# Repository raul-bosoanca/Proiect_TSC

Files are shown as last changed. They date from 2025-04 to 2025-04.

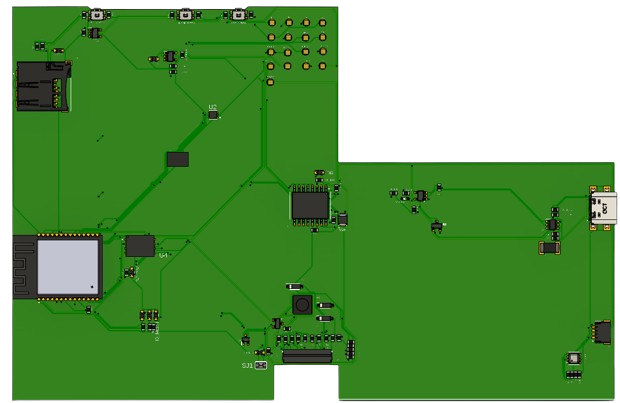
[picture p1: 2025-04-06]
Images/board_top_view.png

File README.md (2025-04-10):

# Proiect_TSC

Diagrama_Block_Openbook drawio

BOM (Bill of Materials):

| Item | Product Link | Datasheet Link |
|---|---|---|
| 112A-TAAR-R03 | [Product](https://store.comet.srl.ro/Catalogue/Product/43497/) | [Datasheet](https://store.comet.bg/download-file.php?id=27596) |
| BD5229G-TR | [Product](https://store.comet.srl.ro/Catalogue/Product/43497/) | [Datasheet](https://datasheet.datasheetarchive.com/originals/distributors/Datasheets_SAMA/f2b9741ef86007909f138d561a359946.pdf) |
| Capacitor 0402 | [Product](https://store.comet.srl.ro/Catalogue/Product/43497/) | [Datasheet](https://componentsearchengine.com/Datasheets/2/CC0402MRX5R5BB106.pdf) |
| CPH3225A | [Product](https://store.comet.srl.ro/Catalogue/Product/43497/) | [Datasheet](https://www.snapeda.com/parts/CPH3225A/Seiko%20Instruments/datasheet/) |
| DS3231SN RTC | [Product](https://store.comet.srl.ro/Catalogue/Product/43497/) | [Datasheet](https://www.snapeda.com/parts/DS3231SN%23/Analog%20Devices/datasheet/) |
| ESP32 WROVER 0805 Capacitor | [Product](https://store.comet.srl.ro/Catalogue/Product/43497/) | [Datasheet](https://ro.mouser.com/datasheet/2/40/schottky-3165252.pdf) |
| ESP32 WROVER BME680 Sensor | [Product](https://store.comet.srl.ro/Catalogue/Product/43497/) | [Datasheet](https://www.snapeda.com/parts/BME680/Bosch%20Sensortec/datasheet/) |
| ESP32 WROVER MCP73831 Power Management | [Product](https://store.comet.srl.ro/Catalogue/Product/43497/) | [Datasheet](https://eu.mouser.com/datasheet/2/268/MCP73831_Family_Data_Sheet_DS20001984H-3441711.pdf) |
| ESP32 WROVER P-Channel MOSFET | [Product](https://store.comet.srl.ro/Catalogue/Product/43497/) | [Datasheet](https://www.diodes.com/assets/Datasheets/DMG2305UX.pdf) |
| ESP32C6 Varistor 1812 | [Product](https://store.comet.srl.ro/Catalogue/Product/43497/) | [Datasheet](https://www.tdk-electronics.tdk.com/inf/75/db/CTVS_14/Surge_protection_series.pdf) |
| ESP32-C6 WROOM-1-N8 | [Product](https://store.comet.srl.ro/Catalogue/Product/43497/) | [Datasheet](https://www.snapeda.com/parts/ESP32-C6-WROOM-1-N8/Espressif%20Systems/datasheet/) |
| FH34SRJ-24S-0.5SH Connector | [Product](https://store.comet.srl.ro/Catalogue/Product/43497/) | [Datasheet](https://www.hirose.com/en/product/document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) |
| LED Chip 0603 | [Product](https://store.comet.srl.ro/Catalogue/Product/43497/) | [Datasheet](https://www.snapeda.com/parts/KP-1608SURCK/Kingbright/datasheet/) |
| MAX17048G+T10 Battery Fuel Gauge | [Product](https://store.comet.srl.ro/Catalogue/Product/43497/) | [Datasheet](https://www.snapeda.com/parts/MAX17048G+T10/Analog%20Devices/datasheet/) |
| MBR0530 Schottky Diode | [Product](https://store.comet.srl.ro/Catalogue/Product/43497/) | [Datasheet](https://www.snapeda.com/parts/MBR0530/ON%20Semiconductor/datasheet/) |
| PGB1010603MR Inductor | [Product](https://store.comet.srl.ro/Catalogue/Product/43497/) | [Datasheet](https://www.snapeda.com/parts/PGB1010603MR/Littelfuse%20Inc./datasheet/) |
| QWIIC Connector | [Product](https://store.comet.srl.ro/Catalogue/Product/43497/) | [Datasheet](https://www.youtube.com/watch?v=dQw4w9WgXcQ) |
| RCL CPOL 3528 | [Product](https://store.comet.srl.ro/Catalogue/Product/43497/) | [Datasheet](https://s3.amazonaws.com/snapeda/datasheet/TAJB475K025RNJ_AVX.pdf) |
| SI1308EDL-T1-GE3 MOSFET | [Product](https://store.comet.srl.ro/Catalogue/Product/43497/) | [Datasheet](https://www.youtube.com/watch?v=dQw4w9WgXcQ) |
| SJ | [Product](https://store.comet.srl.ro/Catalogue/Product/43497/) | [Datasheet](https://www.youtube.com/watch?v=dQw4w9WgXcQ) |
| TPTP20R | [Product](https://store.comet.srl.ro/Catalogue/Product/43497/) | [Datasheet](https://easyeda.com/component/7524403feb2642ac9f9f26dfb93ceacf) |
| USB4110-GF-A USB Hub | [Product](https://store.comet.srl.ro/Catalogue/Product/43497/) | [Datasheet](https://gct.co/files/drawings/usb4110.pdf) |
| USBLC6-2SC6Y USB Surge Protection | [Product](https://store.comet.srl.ro/Catalogue/Product/43497/) | [Datasheet](https://www.snapeda.com/parts/USBLC6-2SC6Y/STMicroelectronics/datasheet/) |
| XC6220A331MR-G Voltage Regulator | [Product](https://store.comet.srl.ro/Catalogue/Product/43497/) | [Datasheet](https://product.torexsemi.com/system/files/series/xc6220.pdf) |

  Hardware Components:

  ESP32-C3-WROOM:
    
    Wi-Fi/BLE connectivity
    Supports SPI, I2C, and UART communication
    Operates at 3.3V, powered by an LDO regulator

  USB-C - Charging & USB communication
  
  MCP73832 - LiPo battery charging management
  
  LDO 3.3V - Supplies power to ESP32 and peripherals
  
  DC/DC 5V - Provides 5V for sensors
  
  BME680 - Enveroment sensor

ESP32 PINOUT:

    IO0 - RTC INT Signal
    IO1 - CLOCK Signal
    IO2 - SPI MISO Signal
    IO3 - EPD BUSY Signal
    IO4 - SD Card Chip Select
    IO5 - EPD DC Signal
    IO6 - SPI SCK Signal
    IO7 - SPI MOSI Signal
    IO9 - BOOT Button Signal
    IO10 - EPD Chip Select
    IO11 - Flash NOR Memory Chip Select
    IO12 - USB D+ Signal
    IO13 - USB D- Signal
    IO15 - CHANGE Button Signal
    GPIO16 - UART TX
    GPIO17 - UART RX
    IO18 - RTC RESET Signal
    IO19 - I2C Sensor VDDIO Signal
    IO20 - EPD 3V3
    IO21 - I2C SDA Signal
    IO22 - I2C SCL Signal
    IO23 - EPD RESET Signal

Note : On the final 3D models i did not render the top and buttom ground planes because the working pc did not have the power to render them

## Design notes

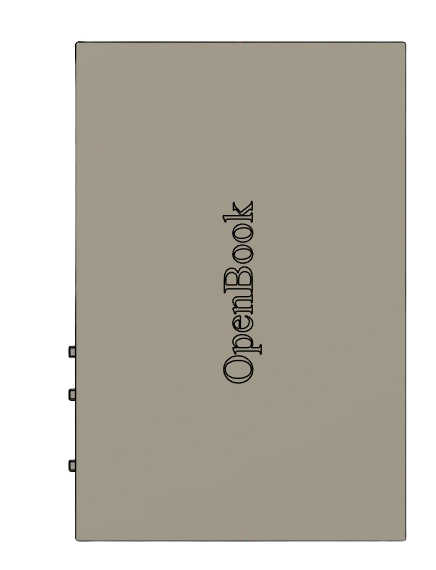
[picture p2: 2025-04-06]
Images/open_book_bottom.png

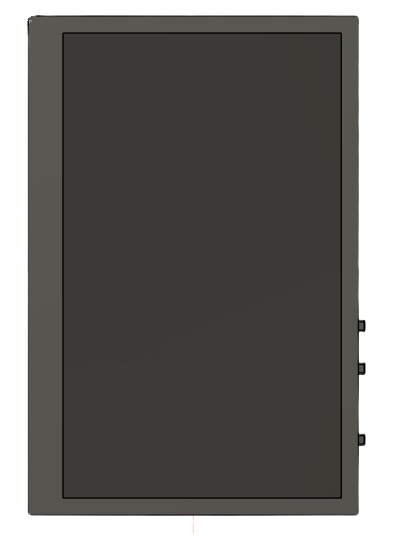
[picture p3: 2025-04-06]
Images/open_book_top.png

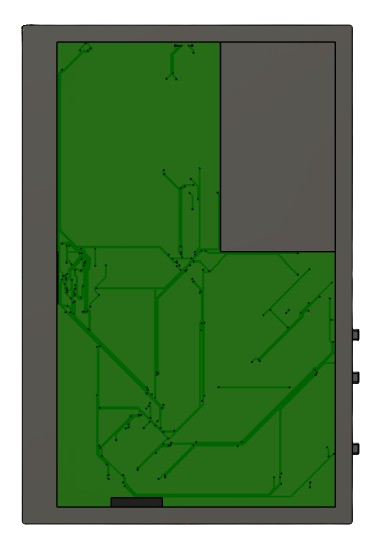
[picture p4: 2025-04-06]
Images/open_book_top_no_screen.png

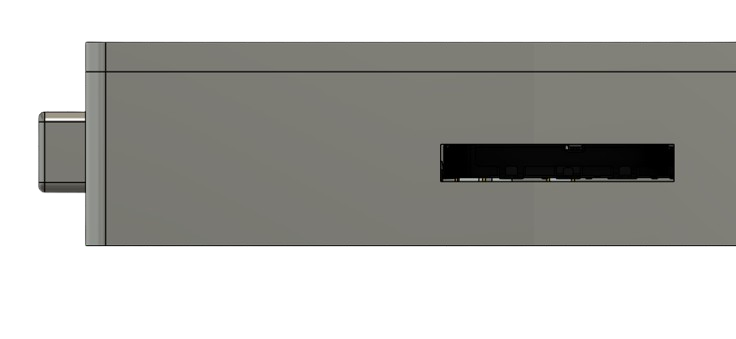
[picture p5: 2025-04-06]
Images/open_book_sd_port.png

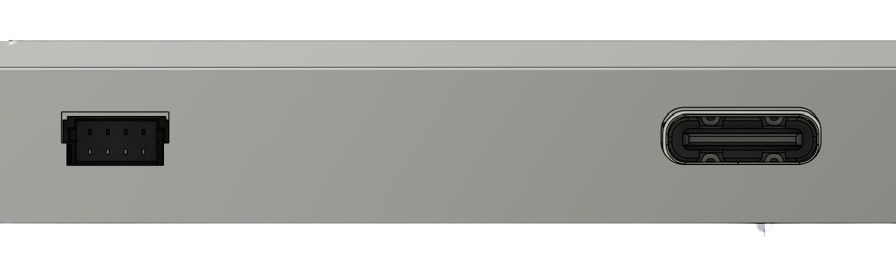
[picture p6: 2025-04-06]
Images/open_book_usb_ports.png

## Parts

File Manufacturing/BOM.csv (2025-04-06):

Qty | Value | Device | Package | Parts | Description | ARROW_PART_NUMBER | ARROW_PRICE-STOCK | AVAILABILITY | CENTROID_NOT_SPECIFIED | CHECK_PRICES | COPYRIGHT | DATASHEET | DESCRIPTION | DIGIKEY_DESCRIPTION | DIGIKEY_PART_NUMBER | HEIGHT | LEAD_FREE | MANUFACTURER_NAME | MANUFACTURER_PART_NUMBER | MF | MFR_NAME | MOUSER_PART_NUMBER | MOUSER_PRICE-STOCK | MOUSER_TESTING_PART_NUMBER | MOUSER_TESTING_PRICE-STOCK | MP | MPN | PACKAGE | POPULARITY | PREFIX | PRICE | PROD_ID | PURCHASE-URL | ROHS | SNAPEDA_LINK | SPICEMODEL | SPICEPREFIX | TEMPERATURE_RANGE_HIGH | TEMPERATURE_RANGE_LOW | TP_SIGNAL_NAME | VALUE
1 |  | ADAFRUIT_LEDCHIP-LED0603 | ADAFRUIT_CHIP-LED0603 | CHG_LED | LED
1 |  | SJ | SJ | SJ1 | SMD solder JUMPER |  |  |  |  |  |  |  |  |  |  |  |  |  |  |  |  |  |  |  |  |  |  |  | 3
1 | 0.47 | ESP32_WROVER_EAGLE-LTSPICE_RR0402 | EAGLE-LTSPICE_C0402 | R4 | RESISTOR, European symbol |  |  |  |  |  |  |  |  |  |  |  |  |  |  |  |  |  |  |  |  |  |  |  |  |  |  |  |  |  |  | NONE | R
1 | 100K | ESP32_WROVER_EAGLE-LTSPICE_RR0402 | EAGLE-LTSPICE_C0402 | R1_PWRUSB | RESISTOR, European symbol |  |  |  |  |  |  |  |  |  |  |  |  |  |  |  |  |  |  |  |  |  |  |  |  |  |  |  |  |  |  | NONE | R
4 | 100nF | EAGLE-LTSPICE_CC0402 | EAGLE-LTSPICE_C0402 | C17, C18, C19, C23 | CAPACITOR, European symbol |  |  |  |  |  |  |  |  |  |  |  |  |  |  |  |  |  |  |  |  |  |  |  |  |  |  |  |  |  |  | NONE | C
2 | 100nF | ESP32_WROVER_EAGLE-LTSPICE_CC0402 | EAGLE-LTSPICE_C0402 | C1, C9 | CAPACITOR, European symbol |  |  |  |  |  |  |  |  |  |  |  |  |  |  |  |  |  |  |  |  |  |  |  |  |  |  |  |  |  |  | NONE | C
2 | 100uF | EAGLE-LTSPICE_CC0402 | EAGLE-LTSPICE_C0402 | C21, C22 | CAPACITOR, European symbol |  |  |  |  |  |  |  |  |  |  |  |  |  |  |  |  |  |  |  |  |  |  |  |  |  |  |  |  |  |  | NONE | C
1 | 100uF | RCL_CPOL-EUCT3528 | RCL_CT3528 | C4 | POLARIZED CAPACITOR, European symbol |  |  |  |  |  |  |  |  |  |  |  |  |  |  |  |  |  |  |  |  |  |  |  | 0 |  |  |  |  |  |  |  | C
7 | 10K | ESP32_WROVER_EAGLE-LTSPICE_RR0402 | EAGLE-LTSPICE_C0402 | R1-PINH1, R2-PINH1, R3, R5, R6, R7, R_CL1 | RESISTOR, European symbol |  |  |  |  |  |  |  |  |  |  |  |  |  |  |  |  |  |  |  |  |  |  |  |  |  |  |  |  |  |  | NONE | R
9 | 10k | ESP32_WROVER_EAGLE-LTSPICE_RR0402 | EAGLE-LTSPICE_C0402 | R_BOOT, R_CHANGE, R_EPD_CS, R_FLASH_CS, R_MISO, R_MOSI', R_RESET, R_SCK, R_SS_SD | RESISTOR, European symbol |  |  |  |  |  |  |  |  |  |  |  |  |  |  |  |  |  |  |  |  |  |  |  |  |  |  |  |  |  |  | NONE | R
1 | 10uF | ESP32_WROVER_EAGLE-LTSPICE_CC0402 | EAGLE-LTSPICE_C0402 | C3 | CAPACITOR, European symbol |  |  |  |  |  |  |  |  |  |  |  |  |  |  |  |  |  |  |  |  |  |  |  |  |  |  |  |  |  |  | NONE | C
1 | 112A-TAAR-R03_ATTEND | 112A-TAAR-R03_ATTEND | 112ATAARR03ATTEND | J2 | Micro SD Card Socket, Push-Push Type, Top Mount, SMT, H=1.83mm, 10u |  |  |  |  |  |  |  | Micro SD Card Socket | Push-Push Type | Top Mount | SMT | H=1.83mm | 10u |  |  | 1.9mm |  | ATTEND | 112A-TAAR-R03 ATTEND
1 | 15 | ESP32_WROVER_EAGLE-LTSPICE_RR0402 | EAGLE-LTSPICE_C0402 | R10 | RESISTOR, European symbol |  |  |  |  |  |  |  |  |  |  |  |  |  |  |  |  |  |  |  |  |  |  |  |  |  |  |  |  |  |  | NONE | R
1 | 1uF | EAGLE-LTSPICE_CC0402 | EAGLE-LTSPICE_C0402 | C20 | CAPACITOR, European symbol |  |  |  |  |  |  |  |  |  |  |  |  |  |  |  |  |  |  |  |  |  |  |  |  |  |  |  |  |  |  | NONE | C
10 | 1uF/50V | EAGLE-LTSPICE_CC0402 | EAGLE-LTSPICE_C0402 | C6, C7, C8, C10, C11, C12, C13, C14, C15, C16 | CAPACITOR, European symbol |  |  |  |  |  |  |  |  |  |  |  |  |  |  |  |  |  |  |  |  |  |  |  |  |  |  |  |  |  |  | NONE | C
1 | 2.2 | ESP32_WROVER_EAGLE-LTSPICE_RR0402 | EAGLE-LTSPICE_C0402 | R2 | RESISTOR, European symbol |  |  |  |  |  |  |  |  |  |  |  |  |  |  |  |  |  |  |  |  |  |  |  |  |  |  |  |  |  |  | NONE | R
1 | 200 | ESP32_WROVER_EAGLE-LTSPICE_RR0402 | EAGLE-LTSPICE_C0402 | R1_BAT | RESISTOR, European symbol |  |  |  |  |  |  |  |  |  |  |  |  |  |  |  |  |  |  |  |  |  |  |  |  |  |  |  |  |  |  | NONE | R
2 | 20V/4.2A/52mO/1.4W | ESP32_WROVER_SPARKFUN-DISCRETESEMI_MOSFET_PCH-DMG2305UX-7 | ESP32_WROVER_SPARKFUN-DISCRETESEMI_SOT23-3 | Q1, Q3 | P-channel MOSFETs |  |  |  |  |  |  |  |  |  |  |  |  |  |  |  |  |  |  |  |  |  |  |  |  |  |  | TRAN-14388 |  |  |  |  |  |  |  |  | 20V/4.2A/52mO/1.4W
1 | 2K | ESP32_WROVER_EAGLE-LTSPICE_RR0402 | EAGLE-LTSPICE_C0402 | R2_BAT | RESISTOR, European symbol |  |  |  |  |  |  |  |  |  |  |  |  |  |  |  |  |  |  |  |  |  |  |  |  |  |  |  |  |  |  | NONE | R
5 | 4.7uF | ESP32_WROVER_EAGLE-LTSPICE_CC0402 | EAGLE-LTSPICE_C0402 | C1_BAT, C1_BAT1, C1_BAT2, C2, C2_BAT | CAPACITOR, European symbol |  |  |  |  |  |  |  |  |  |  |  |  |  |  |  |  |  |  |  |  |  |  |  |  |  |  |  |  |  |  | NONE | C
1 | 4.7uF/25V | ESP32_WROVER_EAGLE-LTSPICE_CC0402 | EAGLE-LTSPICE_C0402 | C5 | CAPACITOR, European symbol |  |  |  |  |  |  |  |  |  |  |  |  |  |  |  |  |  |  |  |  |  |  |  |  |  |  |  |  |  |  | NONE | C
2 | 5k1 | ESP32_WROVER_EAGLE-LTSPICE_RR0402 | EAGLE-LTSPICE_C0402 | R2-USB_5K1, R2-USB_5K2 | RESISTOR, European symbol |  |  |  |  |  |  |  |  |  |  |  |  |  |  |  |  |  |  |  |  |  |  |  |  |  |  |  |  |  |  | NONE | R
1 | 68Uh | 744043680IND_4828-WE-TPC_WRE | IND_4828-WE-TPC_WRE | L1 |  |  |  |  |  |  | Copyright (C) 2024 Ultra Librarian. All rights reserved. |  |  |  |  |  |  |  | 744043680 |  | Wurth Electronics
1 | BD5229G-TR | BD5229G-TR | SOT95P280X125-5N | IC2 | Voltage Detector with Adjustable Delay Time: CMOS processes are utilized to develop high precision, low current consumption CMOS reset ICs that allow arbitrary setting of the delay time. The extensive lineup includes both Nch Open Drain and CMOS output types in a wide range of detection voltages (from 2.3V to 6.0V, in 0.1V steps), enabling selection of the ideal solution based on customer requirements. In addition, the entire series is of course both lead-free and RoHS-compliant. |  |  |  |  |  |  |  | Voltage Detector with Adjustable Delay Time: CMOS processes are utilized to develop high precision | low current consumption CMOS reset ICs that allow arbitrary setting of the delay time. The extensive lineup includes both Nch Open Drain and CMOS output types in a wide range of detection voltages (from 2.3V to 6.0V | in 0.1V steps) | enabling selection of the ideal solution based on customer requirements. In addition | the entire series is of course both lead-free and RoHS-compliant. |  |  | 1.25mm |  | ROHM Semiconductor | BD5229G-TR |  |  | 755-BD5229G-TR | https://www.mouser.co.uk/ProductDetail/ROHM-Semiconductor/BD5229G-TR?qs=4kLU8WoGk0vvnhrrYwdszw%3D%3D
3 | BUTTON_CUSYOMV1 | BUTTON_CUSYOMV1 | MYBUTTON | BOOT_BUTTON, CHANGE_BUTTON, RESET_BUTTON
1 | CPH3225A | CPH3225A | CAPCP3225X100N | C24 | Cap 0.011F 3.3V 1210 Flat Check availability |  |  | Not in stock |  | https://www.snapeda.com/parts/CPH3225A/Seiko+Instruments/view-part/?ref=eda |  |  | 11 mF (EDLC) Supercapacitor 3.3 V 1210 (3225 Metric) - - |  |  |  |  |  |  | Seiko Instruments |  |  |  |  |  | CPH3225A |  | 1210 Seiko |  |  | None |  | https://www.snapeda.com/api/url_track_click_mouser/?unipart_id=562593&manufacturer=Seiko Instruments&part_name=CPH3225A&search_term=None |  | https://www.snapeda.com/parts/CPH3225A/Seiko+Instruments/view-part/?ref=snap
1 | DS3231SN# | DS3231SN# | SOIC127P1032X265-16N | U3 | Real Time Clock Serial 16-Pin SOIC W T/R Check availability |  |  | In Stock |  | https://www.snapeda.com/parts/DS3231SN%23/Analog+Devices/view-part/?ref=eda |  |  | Extremely Accurate I²C-Integrated RTC/TCXO/Crystal |  |  |  |  |  |  | Analog Devices |  |  |  |  |  | DS3231SN# |  | SOIC-16 Maxim |  |  | None |  | https://www.snapeda.com/api/url_track_click_mouser/?unipart_id=99048&manufacturer=Analog Devices&part_name=DS3231SN#&search_term=None |  | https://www.snapeda.com/parts/DS3231SN%23/Analog+Devices/view-part/?ref=snap
1 | ESP32-C6-WROOM-1-N8 | ESP32-C6-WROOM-1-N8 | XCVR_ESP32-C6-WROOM-1-N8 | U1 | Check availability |  |  | In Stock |  | https://www.snapeda.com/parts/ESP32-C6-WROOM-1-N8/Espressif+Systems/view-part/?ref=eda |  |  | Multiprotocol Modules ESP32-C6 module | Wi-Fi 6 in 2.4 GHz band | Bluetooth 5 | Zigbee 3.0 and Thread. ESP34-WROOM Compatible - ENGINEERING SAMPLE |  |  |  |  |  |  | Espressif Systems |  |  |  |  |  | ESP32-C6-WROOM-1-N8 |  | None |  |  | None |  |  |  | https://www.snapeda.com/parts/ESP32-C6-WROOM-1-N8/Espressif+Systems/view-part/?ref=snap
1 | ESP32C6_VARISTORCN1812 | ESP32C6_VARISTORCN1812 | ESP32C6_VARISTOR_CT/CN1812 | R1 | VARISTOR |  |  |  |  |  |  |  |  |  |  |  |  |  |  |  |  |  |  |  |  |  |  |  | 0
2 | ESP32_WROVER_AVX---SD0805S020S1R0_AVX_SD0805S020S1R0_0_0AVX_SD0805S020S1R0_0_0 | ESP32_WROVER_AVX---SD0805S020S1R0_AVX_SD0805S020S1R0_0_0AVX_SD0805S020S1R0_0_0 | ESP32_WROVER_AVX---SD0805S020S1R0_AVX_SD0805S020S1R0_0 | D2, D6 | Schottky Barrier Rectifier Diode |  |  |  | No |  |  | http://datasheets.avx.com/schottky.pdf |  | DIODE SCHOTTKY 20V 1A 0805 | 478-7800-1-ND |  | yes |  |  | AVX |  | 581-SD0805S020S1R0 |  |  |  |  |  | 0805 (2012 metric) |  | D |  |  |  | yes |  |  |  | +125°C | -55°C
1 | ESP32_WROVER_BME680_BME680 | ESP32_WROVER_BME680_BME680 | ESP32_WROVER_BME680_PSON80P300X300X100-8N | SENSOR2 | Integrated Environmental Unit |  |  | Unavailable |  |  |  |  | Integrated Environmental Unit |  |  |  |  |  |  | Bosch Sensortec |  |  |  |  |  | BME680 |  | LGA-8 Bosch Tools |  |  | None
1 | ESP32_WROVER_SPARKFUN-IC-POWER_MCP73831 | ESP32_WROVER_SPARKFUN-IC-POWER_MCP73831 | ESP32_WROVER_SPARKFUN-IC-POWER_SOT23-5 | MCP73831 | MCP73831T Li-Ion, Li-Pol Controller |  |  |  |  |  |  |  |  |  |  |  |  |  |  |  |  |  |  |  |  |  |  |  |  |  |  | IC-09995
1 | FH34SRJ-24S-0.5SH_99_ | FH34SRJ-24S-0.5SH_99_ | FH34SRJ24S05SH99 | J3 | (0.50mm) Surface Mount, Right Angle |  |  |  |  |  |  |  | 24 Position FFC | FPC Connector Contacts | (0.50mm) Surface Mount | Right Angle |  |  | 1.1mm |  | Hirose | FH34SRJ-24S-0.5SH(99) |  |  | 798-FH34SRJ24S05SH99 | https://www.mouser.co.uk/ProductDetail/Hirose-Connector/FH34SRJ-24S-0.5SH99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
1 | MAX17048G+T10 | MAX17048G+T10 | SON50P200X200X80-9N | U2 | Check availability |  |  | In Stock |  | https://www.snapeda.com/parts/MAX17048G+T10/Analog+Devices/view-part/?ref=eda |  |  | 3µA 1-Cell/2-Cell Fuel Gauge with ModelGauge |  |  |  |  |  |  | Analog Devices |  |  |  |  |  | MAX17048G+T10 |  | TDFN-8 Maxim |  |  | None |  | https://www.snapeda.com/api/url_track_click_mouser/?unipart_id=329239&manufacturer=Analog Devices&part_name=MAX17048G+T10&search_term=None |  | https://www.snapeda.com/parts/MAX17048G+T10/Analog+Devices/view-part/?ref=snap
3 | MBR0530 | MBR0530 | SOD3716X135N | D3, D4, D5 | ON SEMICONDUCTOR - MBR0530 - DIODE, SCHOTTKY, 0.5A, 30V, SOD-123 |  |  | In Stock |  | https://www.snapeda.com/parts/MBR0530/Onsemi/view-part/?ref=eda |  |  | Diode Schottky 30 V 500mA Surface Mount SOD-123 |  |  |  |  |  |  | ON Semiconductor |  |  |  |  |  | MBR0530 |  | SOD-123-2 ON Semiconductor |  |  | None |  | https://www.snapeda.com/api/url_track_click_mouser/?unipart_id=179458&manufacturer=ON Semiconductor&part_name=MBR0530&search_term=None |  | https://www.snapeda.com/parts/MBR0530/Onsemi/view-part/?ref=snap
6 | PGB1010603MR | PGB1010603MR | ESP32_WROVER_AVX---SD0805S020S1R0_AVX_SD0805S020S1R0_0 | D_EPD_CS, D_FLASH_CS, D_MISO, D_MOSI, D_SCK, D_SS_SD | Check availability |  |  | In Stock |  | https://www.snapeda.com/parts/PGB1010603MR/Littelfuse/view-part/?ref=eda |  |  | 150V (Typ) Clamp - Ipp Tvs Diode Surface Mount 0603 (1608 Metric) |  |  |  |  |  |  | Littelfuse Inc. |  |  |  |  |  | PGB1010603MR |  | 0603 Littelfuse Inc. |  |  | None |  | https://www.snapeda.com/api/url_track_click_mouser/?unipart_id=5659453&manufacturer=Littelfuse Inc.&part_name=PGB1010603MR&search_term=None |  | https://www.snapeda.com/parts/PGB1010603MR/Littelfuse/view-part/?ref=snap
1 | QWIIC_RIGHT_ANGLE | QWIIC_CONNECTORJS-1MM | JST04_1MM_RA | J4 | SparkFun I2C Standard Qwiic Connector |  |  |  |  |  |  |  |  |  |  |  |  |  |  |  |  |  |  |  |  |  |  |  |  |  |  | CONN-13694 |  |  |  |  |  |  |  |  | QWIIC_RIGHT_ANGLE
1 | SAMACSYS_PARTS_USB4110-GF-A | SAMACSYS_PARTS_USB4110-GF-A | SAMACSYS_PARTS_USB4110GFA | J1 | CONN USB 2.0 TYPE-C R/A SMT |  |  |  |  |  |  |  | CONN USB 2.0 TYPE-C R/A SMT |  |  | 3.26mm |  | GCT (GLOBAL CONNECTOR TECHNOLOGY) | USB4110-GF-A |  |  | 640-USB4110-GF-A | https://www.mouser.co.uk/ProductDetail/GCT/USB4110-GF-A?qs=KUoIvG%2F9IlYiZvIXQjyJeA%3D%3D
1 | SI1308EDL-T1-GE3 | SI1308EDL-T1-GE3 | SOT65P210X110-3N | Q2 | MOSFET N-Ch 30V 1.5A TrenchFET SC70 Vishay Si1308EDL-T1-GE3 N-channel MOSFET Transistor, 1.5 A, 30 V, 3-Pin SC-70 |  |  | In Stock |  | https://www.snapeda.com/parts/SI1308EDL-T1-GE3/Vishay+Siliconix/view-part/?ref=eda |  |  | Si1308EDL-T1-GE3 N-channel MOSFET Transistor | 1.5 A | 30 V | 3-Pin SC-70 | Siliconix / Vishay SI1308EDL-T1-GE3 |  |  |  |  |  |  | Vishay Siliconix |  |  |  |  |  | SI1308EDL-T1-GE3 |  | SOT-323 Vishay Semiconductor |  |  | None |  | https://www.snapeda.com/api/url_track_click_mouser/?unipart_id=274603&manufacturer=Vishay Siliconix&part_name=SI1308EDL-T1-GE3&search_term=None |  | https://www.snapeda.com/parts/SI1308EDL-T1-GE3/Vishay+Siliconix/view-part/?ref=snap
17 | TPTP20R | TPTP20R | TP20R | 3V3, EPD_3V3, EPD_3V3_C, EPD_BUSY, EPD_CS, EPD_DC, EPD_RST, GND, GND', INT_RTC, MISO, MOSI, RX, SCK, TX, VBAT, VBUS | Test pad |  |  |  |  |  |  |  |  |  |  |  |  |  |  |  |  |  |  |  |  |  |  |  | 2
1 | USBLC6-2SC6Y | USBLC6-2SC6Y | SOT95P280X145-6N | D1 | Low Cap. ESD Protection Auto SOT-23-6 STMicroelectronics USBLC6-2SC6Y, Dual Uni-Directional TVS Diode Array, 6-Pin SOT-23 |  |  | In Stock |  | https://www.snapeda.com/parts/USBLC6-2SC6Y/STMicroelectronics/view-part/?ref=eda |  |  | 17V Clamp 5A (8/20µs) Ipp Tvs Diode Surface Mount SOT-23-6 |  |  |  |  |  |  | STMicroelectronics |  |  |  |  |  | USBLC6-2SC6Y |  | SOT-23-6 STMicroelectronics |  |  | None |  |  |  | https://www.snapeda.com/parts/USBLC6-2SC6Y/STMicroelectronics/view-part/?ref=snap
1 | W25Q512JVEIQ | W25Q512JVEIQ | SON127P600X800X80-9N | U4 | Check availability |  |  | In Stock |  | https://www.snapeda.com/parts/W25Q512JVEIQ/Winbond+Electronics/view-part/?ref=eda |  |  | FLASH - NOR Memory IC 512Mb (64M x 8) SPI - Quad I/O 133 MHz 8-WSON (8x6) |  |  |  |  |  |  | Winbond Electronics |  |  |  |  |  | W25Q512JVEIQ |  | Package |  |  | None |  |  |  | https://www.snapeda.com/parts/W25Q512JVEIQ/Winbond+Electronics/view-part/?ref=snap
1 | XC6220A331MR-G | XC6220A331MR-G | SOT95P280X125-5N | IC1 | LDO Voltage Regulators |  |  |  |  |  |  |  | LDO Voltage Regulators |  |  | 1.2mm |  | Torex | XC6220A331MR-G |  |  | 865-XC6220A331MR-G | https://www.mouser.co.uk/ProductDetail/Torex-Semiconductor/XC6220A331MR-G?qs=AsjdqWjXhJ8ZSWznL1J0gg%3D%3D

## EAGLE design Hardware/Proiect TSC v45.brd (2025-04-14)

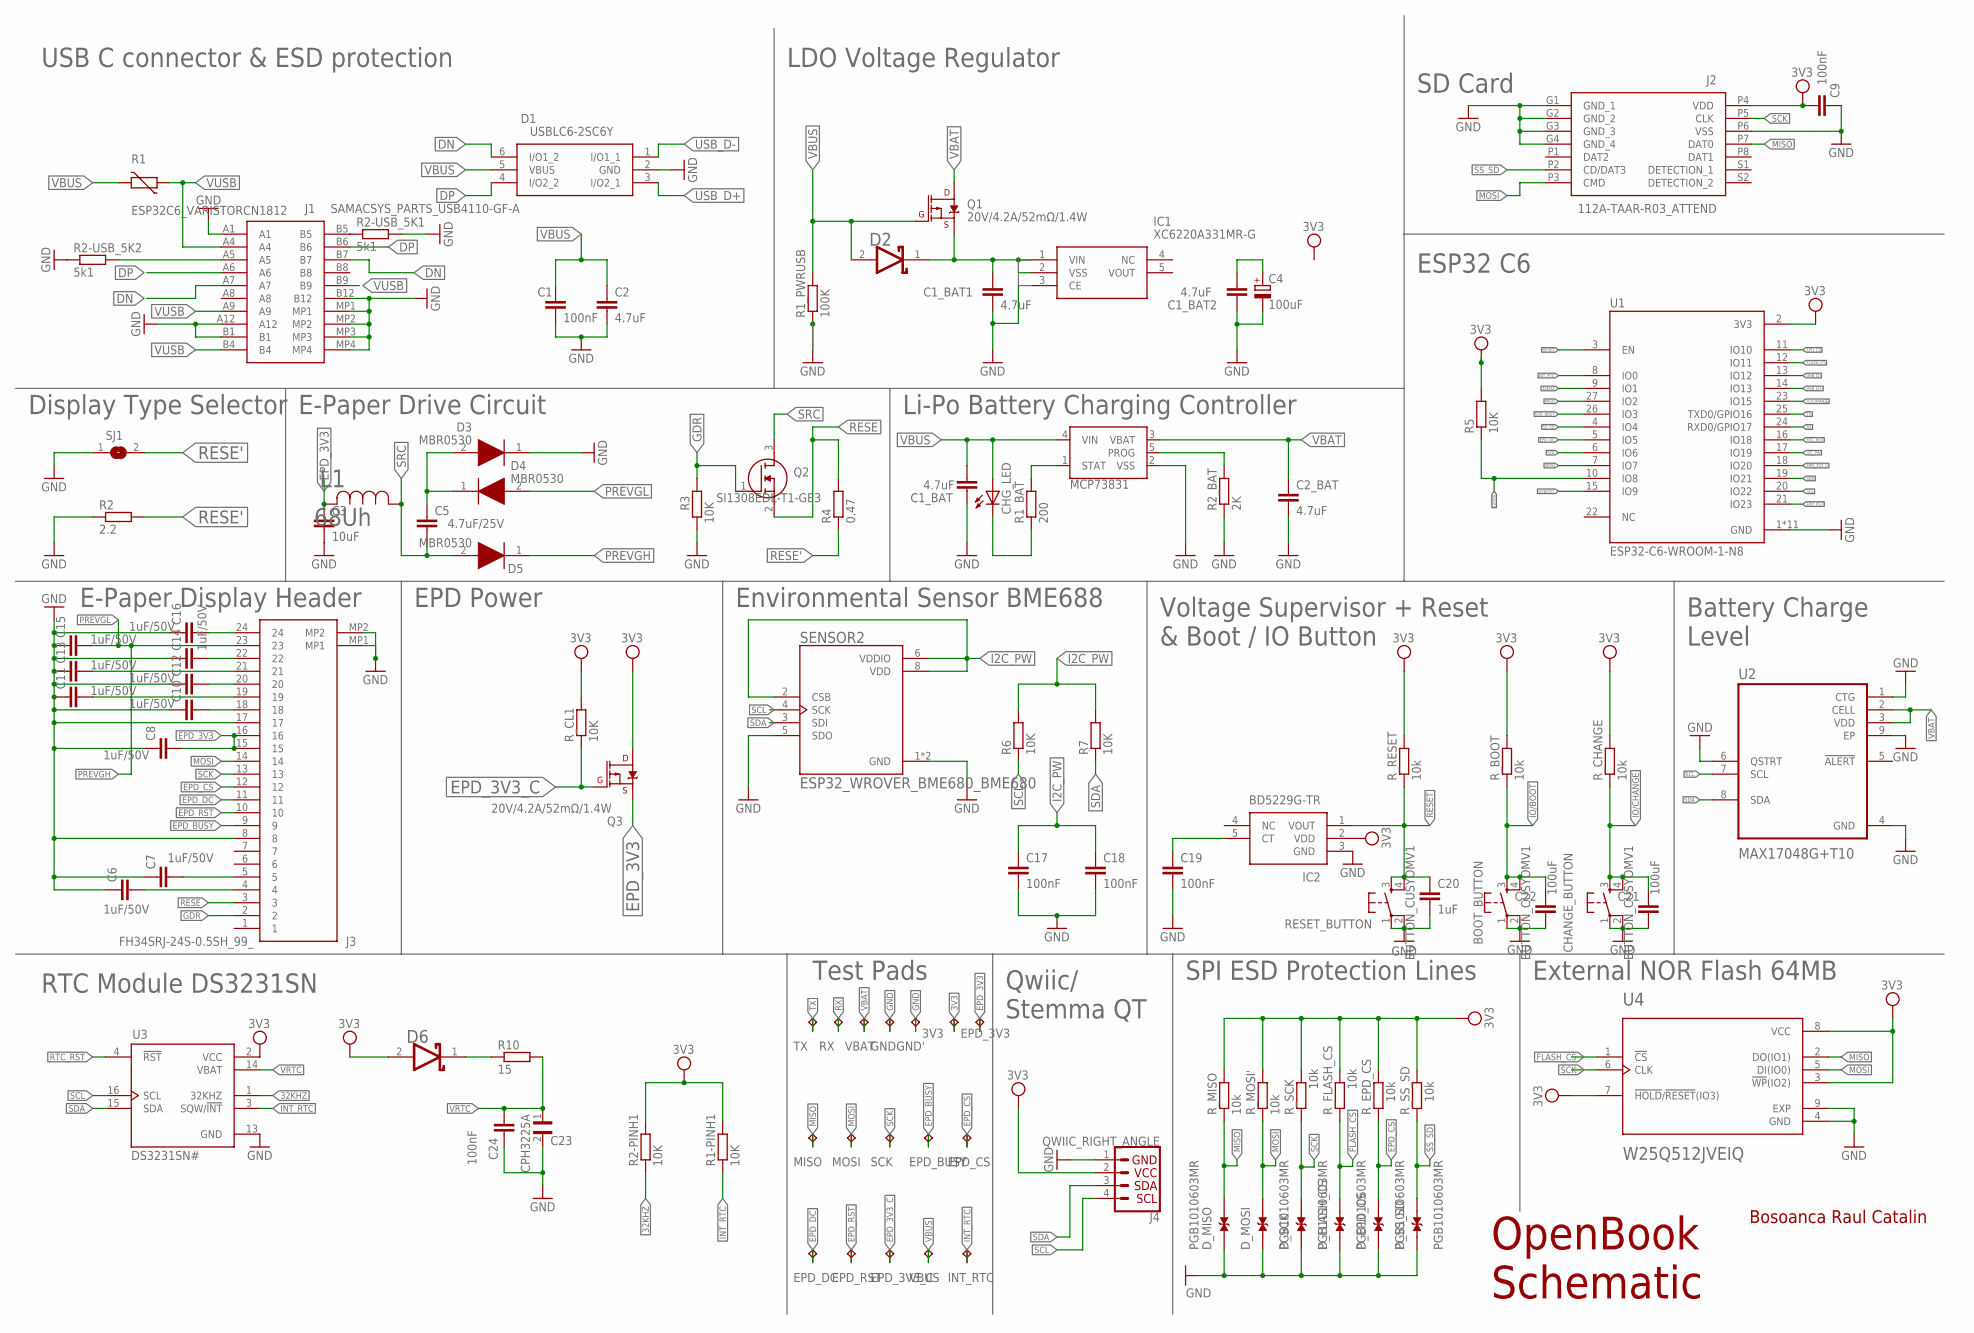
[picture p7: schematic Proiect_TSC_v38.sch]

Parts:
3V3: TPTP20R; TP20R
BOOT_BUTTON: BUTTON_CUSYOMV1; MYBUTTON
C1, C9, C17, C18, C19, C23: 100nF; EAGLE-LTSPICE_C0402
C1_BAT, C1_BAT1, C1_BAT2, C2, C2_BAT: 4.7uF; EAGLE-LTSPICE_C0402
C3: 10uF; EAGLE-LTSPICE_C0402
C4: 100uF; RCL_CT3528
C5: 4.7uF/25V; EAGLE-LTSPICE_C0402
C6, C7, C8, C10, C11, C12, C13, C14, C15, C16: 1uF/50V; EAGLE-LTSPICE_C0402
C20: 1uF; EAGLE-LTSPICE_C0402
C21, C22: 100uF; EAGLE-LTSPICE_C0402
C24: CPH3225A; CAPCP3225X100N
CHANGE_BUTTON: BUTTON_CUSYOMV1; MYBUTTON
CHG_LED: ADAFRUIT_LEDCHIP-LED0603; ADAFRUIT_CHIP-LED0603
D1: USBLC6-2SC6Y; SOT95P280X145-6N
D2, D6: ESP32_WROVER_AVX---SD0805S020S1R0_AVX_SD0805S020S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; ESP32_WROVER_AVX---SD0805S020S1R0_AVX_SD0805S020S1R0_0
D3, D4, D5: MBR0530; SOD3716X135N
D_EPD_CS: PGB1010603MR; ESP32_WROVER_AVX---SD0805S020S1R0_AVX_SD0805S020S1R0_0
D_FLASH_CS: PGB1010603MR; ESP32_WROVER_AVX---SD0805S020S1R0_AVX_SD0805S020S1R0_0
D_MISO: PGB1010603MR; ESP32_WROVER_AVX---SD0805S020S1R0_AVX_SD0805S020S1R0_0
D_MOSI: PGB1010603MR; ESP32_WROVER_AVX---SD0805S020S1R0_AVX_SD0805S020S1R0_0
D_SCK: PGB1010603MR; ESP32_WROVER_AVX---SD0805S020S1R0_AVX_SD0805S020S1R0_0
D_SS_SD: PGB1010603MR; ESP32_WROVER_AVX---SD0805S020S1R0_AVX_SD0805S020S1R0_0
EPD_3V3, EPD_3V3_C: TPTP20R; TP20R
EPD_BUSY: TPTP20R; TP20R
EPD_CS: TPTP20R; TP20R
EPD_DC: TPTP20R; TP20R
EPD_RST: TPTP20R; TP20R
GND: TPTP20R; TP20R
GND': TPTP20R; TP20R
IC1: XC6220A331MR-G; SOT95P280X125-5N
IC2: BD5229G-TR; SOT95P280X125-5N
INT_RTC: TPTP20R; TP20R
J1: SAMACSYS_PARTS_USB4110-GF-A; SAMACSYS_PARTS_USB4110GFA
J2: 112A-TAAR-R03_ATTEND; 112ATAARR03ATTEND
J3: FH34SRJ-24S-0.5SH_99_; FH34SRJ24S05SH99
J4: QWIIC_RIGHT_ANGLE; JST04_1MM_RA
L1: 68Uh; IND_4828-WE-TPC_WRE
MCP73831: ESP32_WROVER_SPARKFUN-IC-POWER_MCP73831; ESP32_WROVER_SPARKFUN-IC-POWER_SOT23-5
MISO: TPTP20R; TP20R
MOSI: TPTP20R; TP20R
Q1, Q3: 20V/4.2A/52mΩ/1.4W; ESP32_WROVER_SPARKFUN-DISCRETESEMI_SOT23-3
Q2: SI1308EDL-T1-GE3; SOT65P210X110-3N
R1: ESP32C6_VARISTORCN1812; ESP32C6_VARISTOR_CT/CN1812
R1-PINH1, R2-PINH1, R3, R5, R6, R7: 10K; EAGLE-LTSPICE_C0402
R1_BAT: 200; EAGLE-LTSPICE_C0402
R1_PWRUSB: 100K; EAGLE-LTSPICE_C0402
R2: 2.2; EAGLE-LTSPICE_C0402
R2-USB_5K1, R2-USB_5K2: 5k1; EAGLE-LTSPICE_C0402
R2_BAT: 2K; EAGLE-LTSPICE_C0402
R4: 0.47; EAGLE-LTSPICE_C0402
R10: 15; EAGLE-LTSPICE_C0402
RESET_BUTTON: BUTTON_CUSYOMV1; MYBUTTON
RX: TPTP20R; TP20R
R_BOOT: 10k; EAGLE-LTSPICE_C0402
R_CHANGE: 10k; EAGLE-LTSPICE_C0402
R_CL1: 10K; EAGLE-LTSPICE_C0402
R_EPD_CS: 10k; EAGLE-LTSPICE_C0402
R_FLASH_CS: 10k; EAGLE-LTSPICE_C0402
R_MISO: 10k; EAGLE-LTSPICE_C0402
R_MOSI': 10k; EAGLE-LTSPICE_C0402
R_RESET: 10k; EAGLE-LTSPICE_C0402
R_SCK: 10k; EAGLE-LTSPICE_C0402
R_SS_SD: 10k; EAGLE-LTSPICE_C0402
SCK: TPTP20R; TP20R
SENSOR2: ESP32_WROVER_BME680_BME680; ESP32_WROVER_BME680_PSON80P300X300X100-8N
SJ1: SJ
TX: TPTP20R; TP20R
U1: ESP32-C6-WROOM-1-N8; XCVR_ESP32-C6-WROOM-1-N8
U2: MAX17048G+T10; SON50P200X200X80-9N
U3: DS3231SN#; SOIC127P1032X265-16N
U4: W25Q512JVEIQ; SON127P600X800X80-9N
VBAT: TPTP20R; TP20R
VBUS: TPTP20R; TP20R

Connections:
3V3: 3V3.TP, C9.1, D6.2 (ANODE), IC2.2 (VDD), J2.P4 (VDD), J4.2, Q3.3 (D), R1-PINH1.2, R2-PINH1.2, R5.2, R_BOOT.2, R_CHANGE.2, R_CL1.2, R_EPD_CS.2, R_FLASH_CS.2, R_MISO.2, R_MOSI'.2, R_RESET.2, R_SCK.2, R_SS_SD.2, U1.2 (3V3), U3.2 (VCC), U4.3 (!WP!(IO2)), U4.7 (!HOLD!/!RESET!(IO3)), U4.8 (VCC)
32KHZ: R2-PINH1.1, U1.9 (IO1), U3.1 (32KHZ)
DN: D1.6 (I/O1_2), J1.A7, J1.B7
DP: D1.4 (I/O2_2), J1.A6, J1.B6
EPD_3V3: C3.1, C8.2, EPD_3V3.TP, J3.15, J3.16, L1.2, Q3.2 (S)
EPD_3V3_C: EPD_3V3_C.TP, Q3.1 (G), R_CL1.1, U1.18 (IO20)
EPD_BUSY: EPD_BUSY.TP, J3.9, U1.26 (IO3)
EPD_CS: D_EPD_CS.2, EPD_CS.TP, J3.12, R_EPD_CS.1, U1.11 (IO10)
EPD_DC: EPD_DC.TP, J3.11, U1.5 (IO5)
EPD_RST: EPD_RST.TP, J3.10, U1.21 (IO23)
FLASH_CS: D_FLASH_CS.2, R_FLASH_CS.1, U1.12 (IO11), U4.1 (!CS)
GDR: J3.2, Q2.1 (G), R3.2
GND: BOOT_BUTTON.1, BOOT_BUTTON.2, C1.2, C1_BAT.2, C1_BAT1.2, C1_BAT2.2, C2.2, C2_BAT.2, C3.2, C4.-, C6.1, C7.1, C8.1, C9.2, C10.1, C11.1, C12.1, C13.1, C14.1, C15.1, C16.1, C17.2, C18.2, C19.2, C20.2, C21.2, C22.2, C23.2, C24.2, CHANGE_BUTTON.1, CHANGE_BUTTON.2, D1.2 (GND), D3.1 (K), D_EPD_CS.1, D_FLASH_CS.1, D_MISO.1, D_MOSI.1, D_SCK.1, D_SS_SD.1, GND.TP, GND'.TP, IC2.3 (GND), J1.A1, J1.A12, J1.B1, J1.B12, J1.MP1, J1.MP2, J1.MP3, J1.MP4, J2.G1 (GND_1), J2.G2 (GND_2), J2.G3 (GND_3), J2.G4 (GND_4), J2.P6 (VSS), J3.8, J3.17, J3.MP1, J3.MP2, J4.1, MCP73831.2 (VSS), R1_PWRUSB.1, R2.1, R2-USB_5K1.2, R2-USB_5K2.1, R2_BAT.1, R3.1, RESET_BUTTON.1, RESET_BUTTON.2, SENSOR2.1 (GND), SENSOR2.5 (SDO), SENSOR2.7 (GND), SJ1.1, U1.1 (GND), U1.28 (GND), U1.29_1 (GND), U1.29_2 (GND), U1.29_3 (GND), U1.29_4 (GND), U1.29_5 (GND), U1.29_6 (GND), U1.29_7 (GND), U1.29_8 (GND), U1.29_9 (GND), U2.1 (CTG), U2.4 (GND), U2.6 (QSTRT), U2.9 (EP), U3.13 (GND), U4.4 (GND), U4.9 (EXP)
GPIO8: R5.1, U1.10 (IO8)
I2C_PW: C17.1, C18.1, R6.2, R7.2, SENSOR2.2 (CSB), SENSOR2.6 (VDDIO), SENSOR2.8 (VDD), U1.17 (IO19)
INT_RTC: INT_RTC.TP, R1-PINH1.1, U1.8 (IO0), U3.3 (SQW/!INT)
IO/BOOT: BOOT_BUTTON.3, BOOT_BUTTON.4, C22.1, R_BOOT.1, U1.15 (IO9)
IO/CHANGE: C21.1, CHANGE_BUTTON.3, CHANGE_BUTTON.4, R_CHANGE.1, U1.23 (IO15)
MISO: D_MISO.2, J2.P7 (DAT0), MISO.TP, R_MISO.1, U1.27 (IO2), U4.2 (DO(IO1))
MOSI: D_MOSI.2, J2.P3 (CMD), J3.14, MOSI.TP, R_MOSI'.1, U1.7 (IO7), U4.5 (DI(IO0))
unnamed: C5.1, D3.2 (A), D4.1 (K)
unnamed: CHG_LED.C, R1_BAT.1
unnamed: J1.B5, R2-USB_5K1.1
unnamed: MCP73831.1 (STAT), R1_BAT.2
unnamed: MCP73831.5 (PROG), R2_BAT.2
unnamed: C6.2, J3.4
unnamed: C19.1, IC2.5 (CT)
unnamed: J1.A5, R2-USB_5K2.2
unnamed: D6.1 (CATHODE), R10.1
unnamed: C7.2, J3.5
unnamed: C10.2, J3.18
unnamed: C1_BAT1.1, D2.1 (CATHODE), IC1.1 (VIN), IC1.2 (VSS), Q1.2 (S)
unnamed: C11.2, J3.19
unnamed: C12.2, J3.20
unnamed: C1_BAT2.1, C4.+
unnamed: C14.2, J3.22
unnamed: C16.2, J3.24
PREVGH: C13.2, D5.1 (K), J3.21
PREVGL: C15.2, D4.2 (A), J3.23
RESE: J3.3, Q2.2 (S), R4.2
RESE': R2.2, R4.1, SJ1.2
RESET: C20.1, IC2.1 (VOUT), RESET_BUTTON.3, RESET_BUTTON.4, R_RESET.1, U1.3 (EN)
RTC_RST: U1.16 (IO18), U3.4 (!RST)
RX: RX.TP, U1.24 (RXD0/GPIO17)
SCK: D_SCK.2, J2.P5 (CLK), J3.13, R_SCK.1, SCK.TP, U1.6 (IO6), U4.6 (CLK)
SCL: J4.4, R6.1, SENSOR2.4 (SCK), U1.20 (IO22), U2.7 (SCL), U3.16 (SCL)
SDA: J4.3, R7.1, SENSOR2.3 (SDI), U1.19 (IO21), U2.8 (SDA), U3.15 (SDA)
SRC: C5.2, D5.2 (A), L1.1, Q2.3 (D)
SS_SD: D_SS_SD.2, J2.P2 (CD/DAT3), R_SS_SD.1, U1.4 (IO4)
TX: TX.TP, U1.25 (TXD0/GPIO16)
USB_D+: D1.3 (I/O2_1), U1.14 (IO13)
USB_D-: D1.1 (I/O1_1), U1.13 (IO12)
VBAT: C2_BAT.1, MCP73831.3 (VBAT), Q1.3 (D), U2.2 (CELL), U2.3 (VDD), VBAT.TP
VBUS: C1.1, C1_BAT.1, C2.1, CHG_LED.A, D1.5 (VBUS), D2.2 (ANODE), MCP73831.4 (VIN), Q1.1 (G), R1.2, R1_PWRUSB.2, VBUS.TP
VRTC: C23.1, C24.1, R10.2, U3.14 (VBAT)
VUSB: J1.A4, J1.A9, J1.B4, J1.B9, R1.1

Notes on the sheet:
USB C connector & ESD protection
LDO Voltage Regulator
SD Card
Display Type Selector
E-Paper Drive Circuit
Li-Po Battery Charging Controller
ESP32 C6
E-Paper Display Header
EPD Power
Environmental Sensor BME688
Voltage Supervisor + Reset & Boot / IO Button
Battery Charge Level
RTC Module DS3231SN
Test Pads
Qwiic/ Stemma QT
SPI ESD Protection Lines
External NOR Flash 64MB
Bosoanca Raul Catalin
OpenBook Schematic

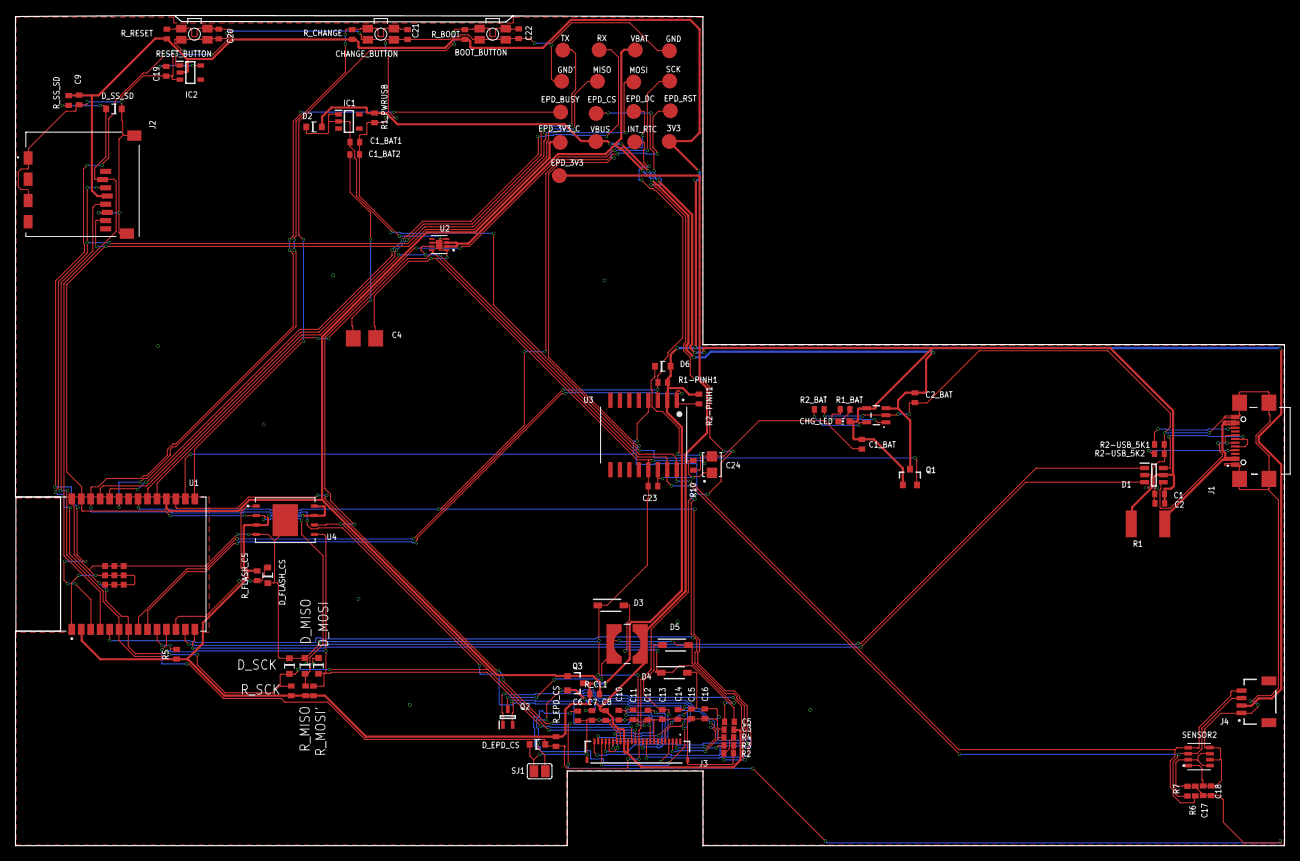
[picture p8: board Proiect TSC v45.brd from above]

Board: 2 copper layers, 170.2 x 111.3 mm, 103 parts (0 on the bottom side), 56 nets.

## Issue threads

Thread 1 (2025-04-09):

[PCB] Traseele au 90 de grade

andreistan26, 2025-04-09:
Unele dintre trasee au unghiuri drepte

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

raul-bosoanca, 2025-04-14:
Solved right angle routes

Closed 2025-04-14.

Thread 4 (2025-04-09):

[PCB] Condensatorul are valoarea gresita

andreistan26, 2025-04-09:
Condensatorul C8 are valoare `1uF/50V` , ar trebui sa fie `0.1uF/50V`

Din schematic:
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

Din specificatie:
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

raul-bosoanca, 2025-04-10:
Changed value of the capacitor to match the specification value

Closed 2025-04-10.

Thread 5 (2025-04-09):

[CASE] PCB-ul intra in carcasa

andreistan26, 2025-04-09:
PCB-ul se intercaleaza cu carcasa pe partea USB-C.

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

raul-bosoanca, 2025-04-14:
Replaced board in case

Closed 2025-04-14.

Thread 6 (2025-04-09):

[PCB] Traseele I2C_PW nu au grosimea corespunzatoare

andreistan26, 2025-04-09:
Traseul `I2C_PW` trebuie sa aiba 0.3mm, prin el este alimentat `SENSOR2`.

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

raul-bosoanca, 2025-04-14:
Solved. Made them 1.5mm

Closed 2025-04-14.

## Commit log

2025-04-06 Added sch and brd files
    [Proiect TSC v45.brd, Proiect_TSC_v38.sch]
2025-04-06 Changed thickness of PCB, ground plane visible
    [Proiect TSC v45.brd]
2025-04-06 Added manufacturing files
    [BOM.csv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]
2025-04-06 Added board as 3d step
2025-04-06 Add BOM with buy links and datasheet
    [Bill_of_Materials(BOM).xlsx]
2025-04-06 added BOM as csv
    [Bill_of_Materials(BOM).csv]
2025-04-10 Update README.md to add BOM table
2025-04-10 update capacitor value
    [Proiect_TSC_v38.sch]
2025-04-14 Solved bugs of routes, GND pour and silkscreen
    [PCB.brd, Schematic.sch]
2025-04-14 Add files via upload
    Solved bugs on routes, GND pour and silkscreen
    [Proiect TSC v45.brd, Proiect_TSC_v38.sch]
2025-04-15 Solved wrong routes, added ground plane, fixed silkscreen
    [Proiect TSC v45.brd, Proiect_TSC_v38.sch]

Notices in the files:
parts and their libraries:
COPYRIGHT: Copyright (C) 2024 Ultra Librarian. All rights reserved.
